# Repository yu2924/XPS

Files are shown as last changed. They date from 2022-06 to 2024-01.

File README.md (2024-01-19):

# XPS

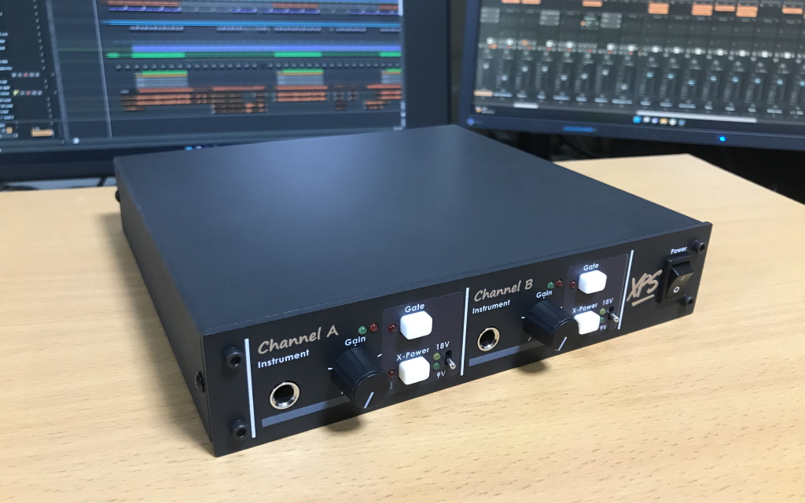
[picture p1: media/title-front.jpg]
  

ハードウェアプロジェクト**XPS**のデザインについてまとめます。

<!-- TOC -->

- [XPS](#xps)
  - [1. 概要](#1-概要)
  - [2. ツールとマテリアル](#2-ツールとマテリアル)
  - [3. 回路の略解](#3-回路の略解)
    - [3-1. 主電源 (XPS:PS-AC, XPS:PS-DC)](#3-1-主電源-xpsps-ac-xpsps-dc)
    - [3-2. バッファアンプ (XPS:Channel)](#3-2-バッファアンプ-xpschannel)
    - [3-3. 給電回路 (XPS:Channel:XPower)](#3-3-給電回路-xpschannelxpower)
    - [3-4. コントローラ (XPS:Channel:Controller) とファームウェア](#3-4-コントローラ-xpschannelcontroller-とファームウェア)
  - [4. 筐体と組み立て](#4-筐体と組み立て)
  - [補遺](#補遺)
  - [Appendix 1. 電気楽器の外側から給電する仕組み](#appendix-1-電気楽器の外側から給電する仕組み)
  - [Appendix 2. レギュレータの損失のシミュレーション](#appendix-2-レギュレータの損失のシミュレーション)
  - [Appendix 3. 平衡ドライバの素子感度](#appendix-3-平衡ドライバの素子感度)
  - [Appendix 4. フリーソフトでCMYKデータを出力する手順](#appendix-4-フリーソフトでcmykデータを出力する手順)

## 1. 概要

**XPS**はDTM用途を想定した、電気ギターなどの電気楽器をオーディオ機器の平衡ライン入力に接続するためのフロントエンドです。ハイインピーダンスのバッファアンプと、アクティブサーキットのための給電回路 [(Appendix 1)](#appendix-1-電気楽器の外側から給電する仕組み) を備えます。

* 独立2チャネル
* 1Uハーフラックサイズ
* AC電源: 100～115V|200～230V切替

**バッファアンプ**[^1]
* 入力インピータンス: 1MΩ typ.
* ゲイン可変範囲: 0～20dB typ.
* 入力スイング幅: ±7.0V typ.
* 出力スイング幅: ±9.9V typ.
* バンド幅: 1～1MHz typ. @Gain=0dB
* クリックレスミュート機能
* トランスレス平衡ライン出力、片極を接地してシングルエンド動作可能、600Ω 1μFの負荷を安定してドライブ可能 (要確認)

[^1]: 入出力のスイング幅やバンド幅は採用したオペアンプの種類に依存する

**給電回路**
* 出力電圧: 9V|18V切替
* 電流制限: 100mA/チャネル typ.
* 短絡・過熱・逆電圧・逆電流に対する保護

## 2. ツールとマテリアル

**ソフトウェアツール**
* 回路シミュレーション: [LTspice](https://www.analog.com/jp/design-center/design-tools-and-calculators/ltspice-simulator.html) XVII
* 回路作図: [BSch3V](https://www.suigyodo.com/online/schsoft.htm) 0.83.05
* PCB設計: [KiCad](https://www.kicad.org/) 6.0
* ファームウェア開発: [MPLAB X IDE](https://www.microchip.com/en-us/tools-resources/develop/mplab-x-ide) v6.00, [Atmel AVR GNU Toolchain](https://www.microchip.com/en-us/tools-resources/develop/microchip-studio/gcc-compilers) v3.62
* 筐体作図: [QCAD](https://qcad.org/) 3.27
* 筐体印刷データ作画: [Inkscape](https://inkscape.org/) 1.1
* 筐体印刷データCMYK出力: [Scribus](https://www.scribus.net/) 1.5.7
* 部品の3Dモデリング: [OpenSCAD](https://openscad.org/) 2021.01

**ハードウェアツール**
* AVRプログラマ: [MPLAB SNAP](https://www.microchip.com/en-us/development-tool/PG164100) or [MPLAB PICkit™ 4](https://www.microchip.com/en-us/development-tool/PG164140)、MPLAB X IDEと互換性のあるISPライタなら何でも
* DC電圧計: 電源回路の出力電圧を調節するために必要ですが、とりあえず3 1/2桁のDMMで十分です。
* オシロスコープ: 発振やオーバーシュートを観察するためにはアナログ帯域が少なくとも10MHz程度必要です。

**CMYK ICCプロファイル**
* [JapanColor2011 ICCプロファイル](https://japancolor.jp/icc.html)

**ブラシフォント**
* [Free Hey November Brush Font](https://www.behance.net/gallery/86877867/Free-Hey-November-Brush-Font)

**その他**
* ハンダとハンダゴテ、ニッパーとラジオペンチ、ヤスリ、3Dプリンタ、等々
* ビニル絶縁電線、スペーサー、ネジ、ワッシャー、アルミ板、等々

## 3. 回路の略解

[回路図](media/schematics.pdf)

### 3-1. 主電源 (XPS:PS-AC, XPS:PS-DC)

* トロイダルトランスを採用
* 古典的なドロッパ方式による11V・22Vの2レール、300mA出力
* レギュレータICにLT1963AとLT3015を採用
* 軽負荷時にレギュレータICの耐圧不足を補う電圧リミッタ

AC入力電圧範囲をなるべく広く取るため、出力電圧が低めのトランスとLDOを組み合わせ、リプル下限をなるべく持ち上げておくために平滑キャパシタは大きめに取っています。

レギュレータ回路の放熱について。ACライン電圧の許容範囲とトランスの変動率から、レギュレータ回路の入力電圧は幅広く変化します。負荷が重くなるほどトランスにおける電圧降下が大きくなるので、レギュレータ回路自体の損失が最大化するのは必ずしも負荷が最大の時ではありません。正確な値を求めるためには負荷変動とトランスの変動率をモデル化したシミュレーションが必要です [(Appendix 2)](#appendix-2-レギュレータの損失のシミュレーション)。
とはいえ、レギュレータ回路における損失の最悪値として {最大電圧降下×最大負荷電流} を考えてもそれほど大きな値ではないので、シャーシにしっかり熱結合させておけばヒートシンクとして十分です。元よりラックマウントする運用形態においてはシャーシ内の空気の循環は期待できないので、排熱は直接シャーシに逃がす以上に確実な方法はありません。

### 3-2. バッファアンプ (XPS:Channel)

* 単電源動作
* JFET入力オペアンプOPA1641[^2] を採用した非反転可変ゲインのヘッドアンプ
* オペアンプOPA1602[^3]を採用したトランスレス平衡ラインドライバ[^4]
* フォトリレーを使用したトランスミッションゲート

[^2]: JFET入力タイプのシングルオペアンプのLF356、OPA604などで代替可能 (要確認)
[^3]: ドライブ能力の高いデュアルオペアンプのNE5532、NJM4580などで代替可能 (要確認)
[^4]: モノリシックICで類似のものにはPMI (現ADI) SSM2142、TI DRV134、THAT 1646などがある

単電源動作ではグラウンドにリターン電流が流れるため音質の面では不利ですが、Hi-Fiオーディオが目的ではないので良しとします。

ラインドライバの差動バランスについて素子感度が高いので注意が必要です [(Appendix 3)](#appendix-3-平衡ドライバの素子感度)。理想的にはホットとコールドは互いに逆位相で等振幅になりますが、抵抗値のばらつきにより振幅のバランスが崩れます。差動ゲインが保たれているのであれば少々のアンバランスは問題になりませんが、大きく崩れるとスイング幅が狭まります。抵抗値の比が重要なので相対精度を保証された集合抵抗を利用するのが良さそうですが、ここでは入手性とパターン引き回しの容易さを重視して、ディスクリート抵抗の組み合わせを選別する方法を採用しました。

ラインドライバの位相補償キャパシタは10pFとしていますが、最適値は採用するオペアンプの種類によって異なります。小さ過ぎると発振し易くなります。基板単体で安定していても、ケーブルを接続すると数MHzの高周波で発振することがあります。大き過ぎると高域特性を鈍らせますが、不要な帯域を欲張るよりは安全側に倒しておくのも一法です。100pFでは100kHz程度でロールオフします。

給電回路のON/OFF操作により電気楽器側でポップ雑音の発生が予想できるので、適宜ミュート出来るようにトランスミッションゲートを設けます。フォトリレーを使用し、定電流ドライブに時定数を掛けることで遷移の際のクリック雑音を防ぎます。フォトリレーはゲート電位がフローティングしているため、信号の振幅に依存したON抵抗の変動は無く、歪みは発生しません。

### 3-3. 給電回路 (XPS:Channel:XPower)

* 2系統の電源レールを切り替えるマルチプレクサ
* レギュレータICにLT3066を採用
* ロジックインターフェース

制御可能なシャットダウン、設定可能な電流制限、パワーグッドフラグを備えます。既成のレギュレータICを採用するのはディスクリートと較べて簡単なのはもちろん、電流制限、熱制限、逆電流保護、逆出力保護など各種保護回路の充実も利点です。

### 3-4. コントローラ (XPS:Channel:Controller) とファームウェア

AVRマイコンのATtiny44Aでピークインジケータとスイッチ入力を制御します。クロックの飛び移りを低減するためなるべく低周波・低電圧で動作させるのが望ましいですが、当デザインでは8MHz 3.3V駆動としています[^5]。
* 信号レベル監視のためADCをフリーランモード、およそ19kHzのサンプリングレートで動作させます。ADC割り込みハンドラにおいて波形処理します。
* チャタリング除去のため、メインループにおいてスイッチ入力をおよそ5msの間隔でポーリングします。ポーリング間隔はADC割り込みをカウントして作り出します。
* 電気楽器側で発生するポップ雑音を自動的に遮断するため、給電回路のON/OFFや電圧切り替え時にトランスミッションゲートを連動します。
* 給電回路のパワーグッドフラグと主電源の電圧を監視し、保安動作をします。

[^5]: ブレッドボードでの簡易的な実験では、3.3V駆動の場合には5V駆動と比較してクロック由来の16MHzのスペクトルが6dB程度低下した

## 4. 筐体と組み立て

筐体はアルミの箱にアルミパネルを組み合わせた二重パネル構造で、ジャックやポテンショメータの固定ナットを隠蔽してすっきりさせます (図4-1)。見栄えは向上しますが[^6]、コストも上がります。製作例ではタカチ社のカスタム加工サービスを利用し、シャーシにはMBFシリーズ、アルミパネルにはNPシリーズを組み合わせました。インクジェット印刷が利用できますが、CMYK色データの用意が必要です[(Appendix 4)](#appendix-4-フリーソフトでcmykデータを出力する手順)。  
スペーサやスイッチキャップ、治具などの作成には3Dプリンタを活用します。  
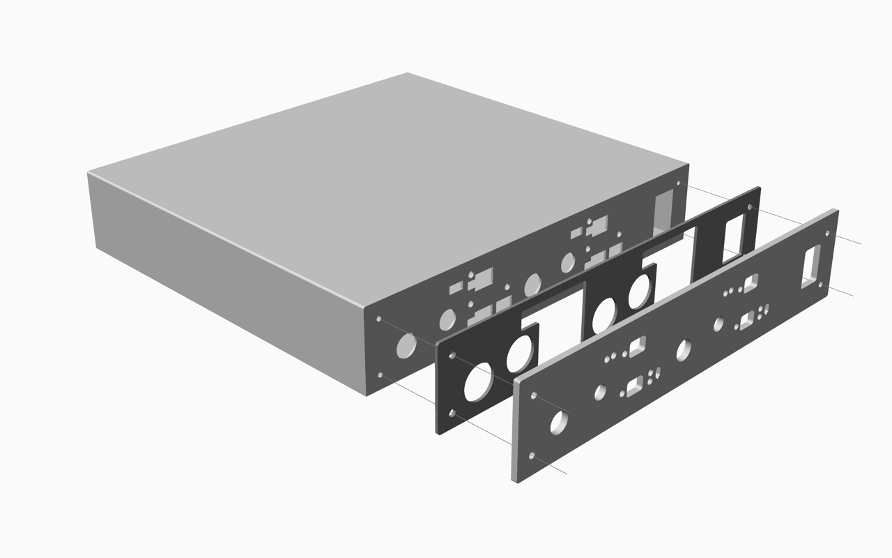
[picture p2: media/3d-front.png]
  
**図4-1. 二重パネル構造**  

[^6]: 個人の主観による



**図4-2. 基板の組み込み**  

主電源レギュレータ基板 (XPS:PS-DC) はアルミブロックを介してシャーシと熱結合します(図4-3, 4-4)。  
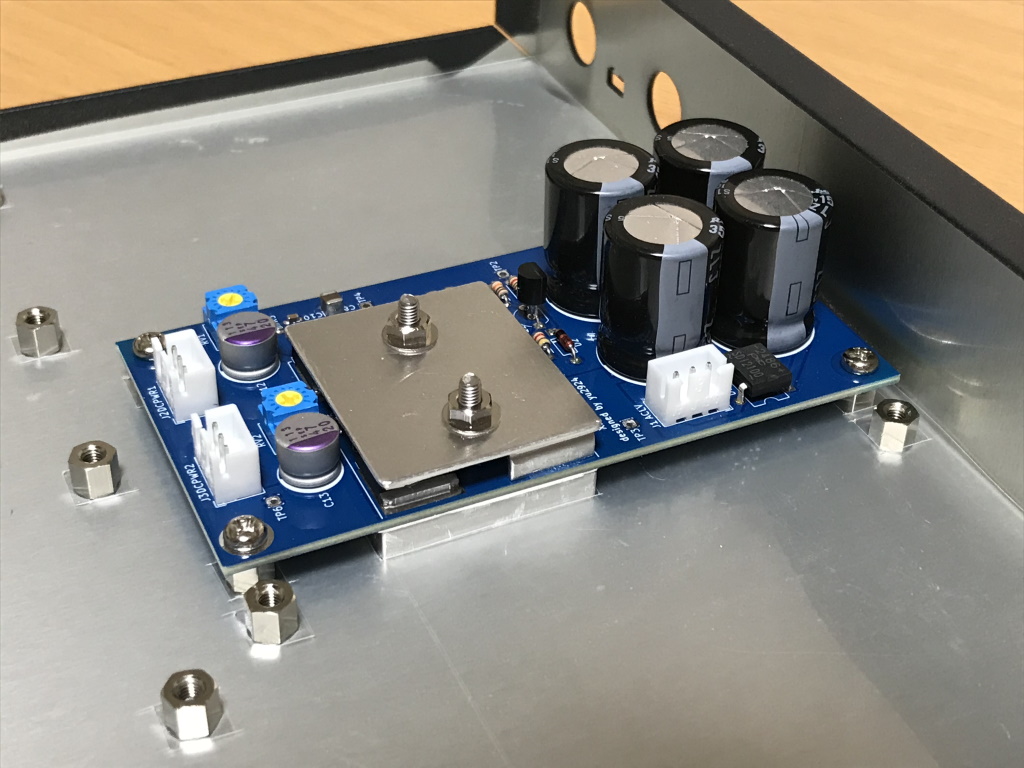
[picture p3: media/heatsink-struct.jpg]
   
**図4-3, 4-4. 主電源のヒートシンク構造**  

バッファアンプ基板 (XPS:Channel) と 出力ジャック基板 (XPS:OutputConnector) では、ジャックやポテンショメータをハンダで固定する際にプリントしたスペーサを合わせて、穴位置のずれを防ぎます (図4-5)。  
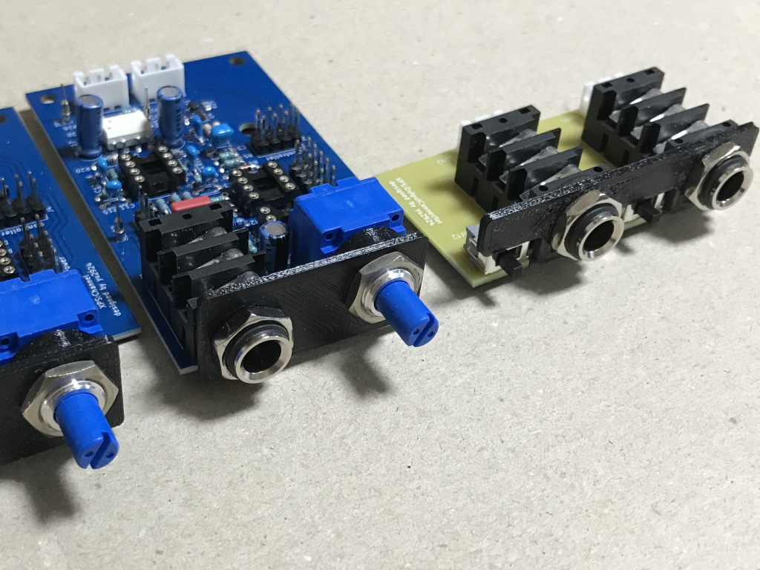
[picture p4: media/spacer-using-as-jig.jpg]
  
**図4-5. スペーサを固定治具として使用**  

ジャックやポテンショメータはシャーシマウントとし、ケーブルの挿抜やツマミ操作がハンダ部分に機械的なストレスを与えにくい構造です (図4-6)。  
  
**図4-6. ジャックやポテンショメータを直接シャーシに固定**  

給電回路基板 (XPS:Channel:XPower) とコントローラ基板 (XPS:Channel:Controller) は、バッファアンプ基板 (XPS:Channel)の子基板としてピンヘッダ・ソケットを介して接続します。(図4-7)  
  
**図4-7. 子基板の装着**  

操作パネル基板 (XPS:Channel:ControlPanel) の組み立てには、治具をプリントしてLEDとスイッチの位置決めに使います。(図4-8, 4-9)  
コントローラ基板 (XPS:Channel:Controller) とはフラットケーブルで接続します。  
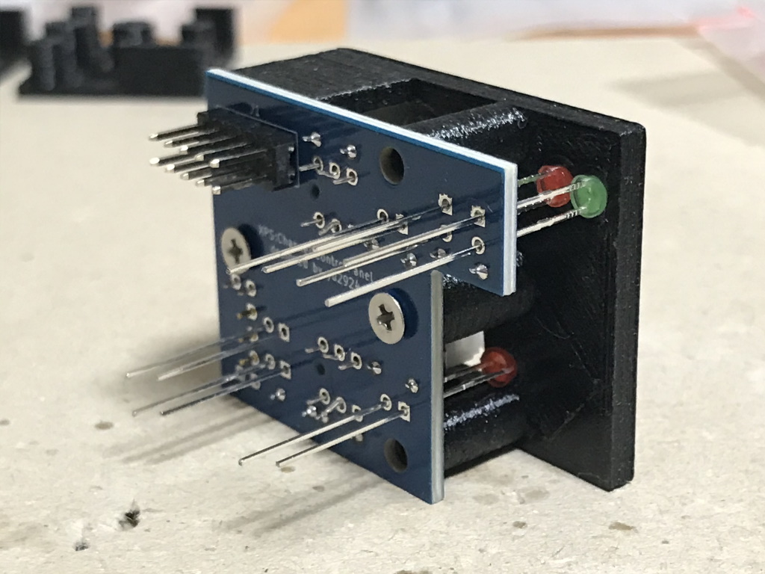
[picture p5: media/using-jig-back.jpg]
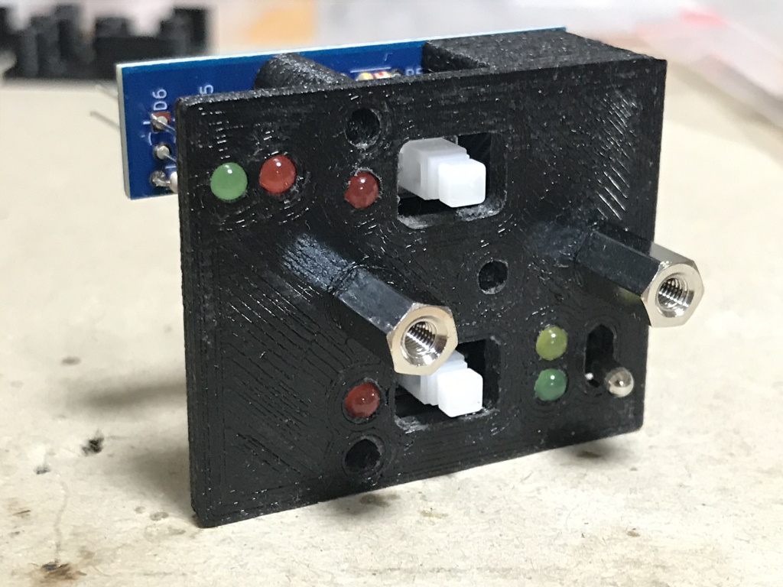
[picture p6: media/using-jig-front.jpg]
   
**図4-8, 4-9. 治具を使用した位置決め**  

フロントパネルはM3ボルトでシャーシに固定します。ハーフラックトレイに乗せるため、シャーシの底面を2mmほど浮かすようになっています (図4-10)。  
  
**図4-10. フロントパネル構造**  

**組み立て後の調節手順**
1. 主電源レギュレータ基板 (XPS:PS-DC) の出力電圧を調節する。あらかじめRV1とRV2を左手最小位置に回し切っておき、主電源をONにする。最初にRV1で11Vレールを調節し、次にRV2で22Vレールを調節する。11Vレールは9V給電のために最低でも11Vあった方が良いが、22Vレールは実際には21V程度あれば十分である。
2. ファームウェアを書き込む。主電源を入れた状態でコントローラ基板 (XPS:Channel:Controller) のISPヘッダにAVRライタを接続し、書き込む。
3. 給電回路基板 (XPS:Channel:XPower) の出力電圧を調節する。あらかじめRV1とRV2を左手最小位置に回し切っておき、給電回路をONにする。最初にRV1で9Vを調節し、次にRV2で18Vを調節する。厳密である必要は無く、長いケーブルを介して給電することを考えると少し高めに設定しておいても良いのではないかと思う。  
:warning:18V側の上がり過ぎに注意する。給電回路に採用した**LT3066の最大定格出力は20Vである**ため、過渡的なオーバーシュートを含め20Vを超えてはいけない。
4. ピークインジケータの感度を調節する。バッファアンプ基板 (XPS:Channel) にオーディオ信号を入力し、テストポイントTP3において±7Vpeakにスイングしたときにインジケータの赤ランプが点灯するようにコントローラ基板 (XPS:Channel:Controller) のRV1を調節する。

---

## 補遺

今後の課題や改良点などを追記します。

**トランスミッションゲートのフィードスルー抑止**

フォトリレーを利用したトランスミッションゲートにおいて、カットオフ減衰率の不足を感じることがありました。ハイゲインの歪みプロセッサに入力した場合などで特に顕著で、漏れてくる音がはっきり聞こえます。もう一組のフォトリレーで双投スイッチを構成することにより改善できるはずです。



**正負両電源化**

今回の制作では電源レールの数を抑えるため、バッファアンプを単電源動作させることになりました。電源レールを増やすにはトランスの独立した2次巻線がレールの数だけ必要です。今回は簡単確実なドロッパ電源を利用しましたが、スイッチング電源の導入も検討して良いと思います。

---

## Appendix 1. 電気楽器の外側から給電する仕組み

アクティブサーキットを内蔵した電気ギターなどの電気楽器によく見られる仕組みとして、出力のTRSジャックにTSプラグを差し込むことでsleeve端子とring端子を短絡させ、バッテリー接続をONするものがあります (図A1-1)。  
  
**図A1-1. TRSジャックを使ったバッテリースイッチ**  

このような仕組みにおいては、バッテリーの代わりに短絡クリップ (図A1-2) を繋いでおけば、TRSケーブルのring端子を経由してアクティブサーキットに給電することができます (図A1-3)。楽器の改造は必要ありません。当デザインではこの方法を採用しています。  
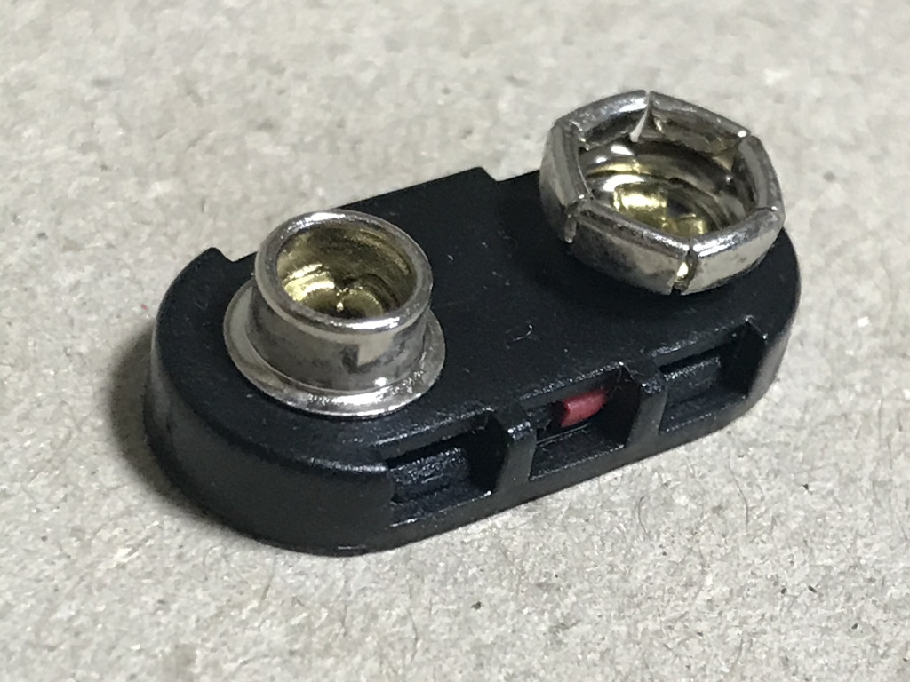
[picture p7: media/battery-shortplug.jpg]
  
**図A1-2. バッテリースナップを加工して作成した短絡クリップの例**  
  
**図A1-3. TRSケーブルを使った外部からの給電**  

>市販の製品の中にも、同様な方法でアクティブサーキットに給電できるものがありました。(要確認)
>* [EMG Power Supplies](https://www.emgpickups.com/parts/power-supplies.html)
>* Line6 Variax XPS-AB, XPS-Mini, XPS-DI
>* Steinberger A-100 Phantom Power Supply

一方、絶縁された連動スイッチでバッテリー接続をONするタイプの電気楽器も存在します (図A1-4)。このような仕組みでは、ジャックを介して外部から給電することは出来ません。  
  
**図A1-4. 絶縁された連動スイッチによるバッテリースイッチ**  

## Appendix 2. レギュレータの損失のシミュレーション

レギュレータの放熱方法について検討するため、パワー半導体における損失をシミュレーションしてみます。  
トランスの変動率仕様あるいは実測値からおよその巻線抵抗を割り出して設定します。回路は実際のものと全く同じである必要はありません。入出力電位差と負荷電流を揃えれば損失の値はおのずと等しくなります。ここで負荷を0～300mAまでスイープさせてみます。(図A2-1)  
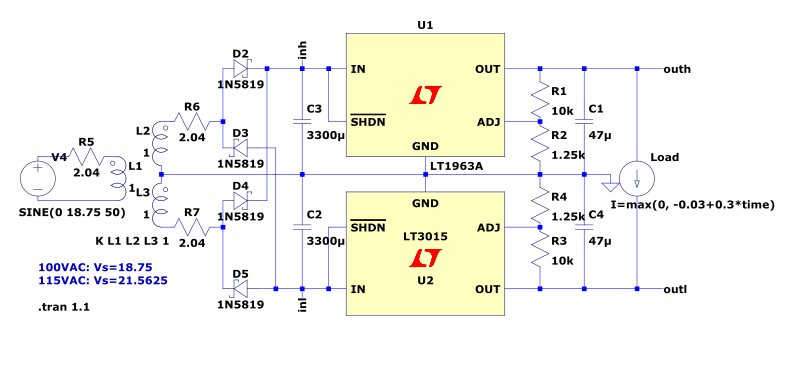
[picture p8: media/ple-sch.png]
  
**図A2-1. 損失シミュレーション回路**  

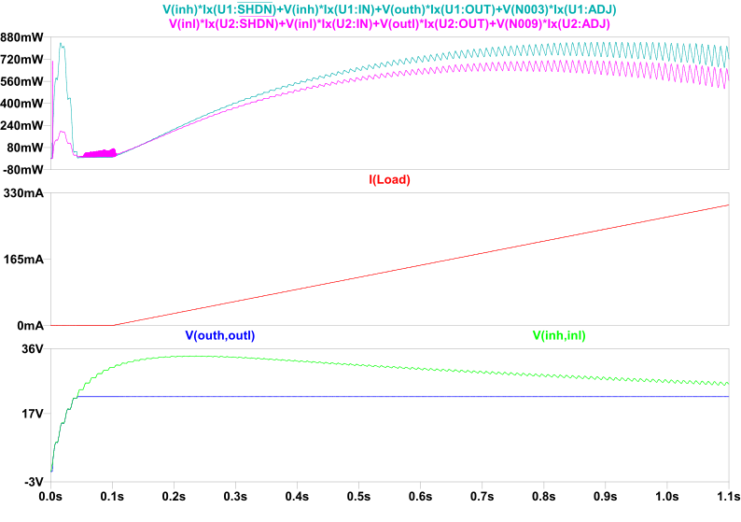
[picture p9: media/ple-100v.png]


**図A2-2. 損失シミュレーション (100V AC)**  

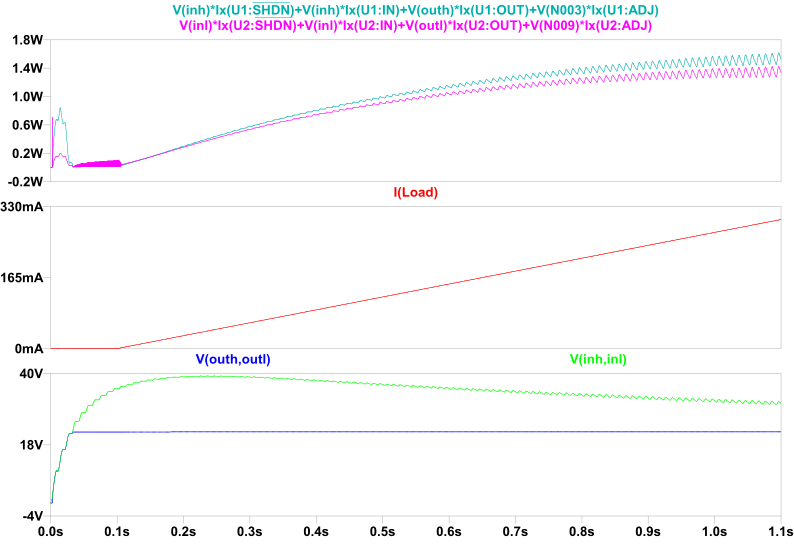
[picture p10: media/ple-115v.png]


**図A2-3. 損失シミュレーション (115V AC)**  

2つのレギュレータICにおける最大損失はおよそ以下の表のように読み取れます。

| |LT1963A|LT3015|
|---|---:|-----:|
|100V AC (図A2-2)|  750mW| 630mW|
|115V AC (図A2-3)| 1.5W|  1.3W|

これらの値を元に、許容可能な温度上昇と放熱経路の熱抵抗を勘案して放熱の仕組みを決定します。

## Appendix 3. 平衡ドライバの素子感度

平衡ドライバにおいて抵抗値のばらつきが差動バランスに与える影響をシミュレーションしてみます。
差動アンプ対の8本の抵抗に0.1%のばらつきを加えてモンテカルロ解析します (図A3-1)。オペアンプモデルにはTI社の提供するPSpiceモデルを利用していますが、理想オペアンプや他のモデルでも構いません。  
ばらつきの無い理想状態ではバランスが取れており、V(hot)とV(cold)の両極は互いに逆位相で等振幅です (図A3-2)。  
ばらつきを加えた場合には差動振幅 V(hot,cold) にはあまり影響を与えないものの、両極の振幅バランスが崩れることがわかります (図A3-3)。  
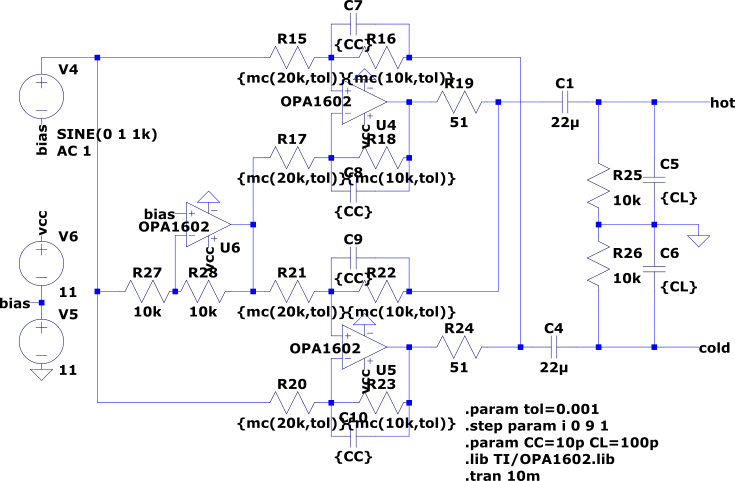
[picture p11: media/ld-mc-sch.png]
  
**図A3-1. モンテカルロ解析する回路**

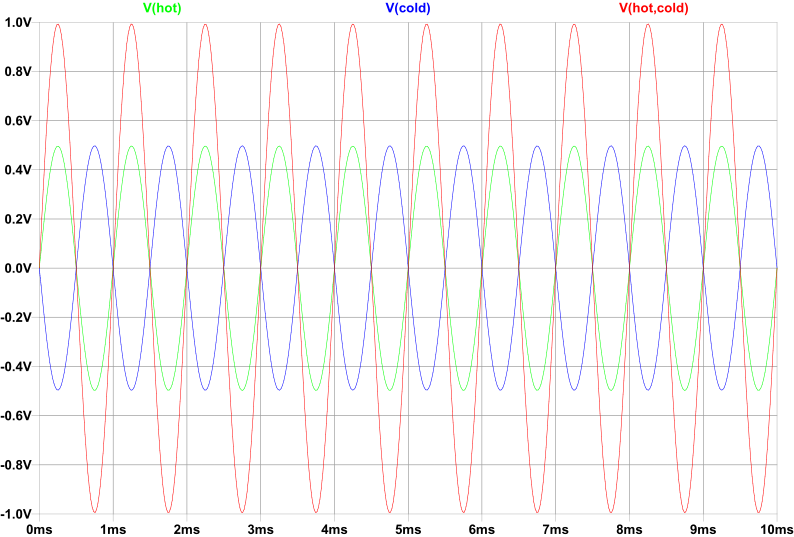
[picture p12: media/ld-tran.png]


**図A3-2. ばらつきの無い理想状態**  

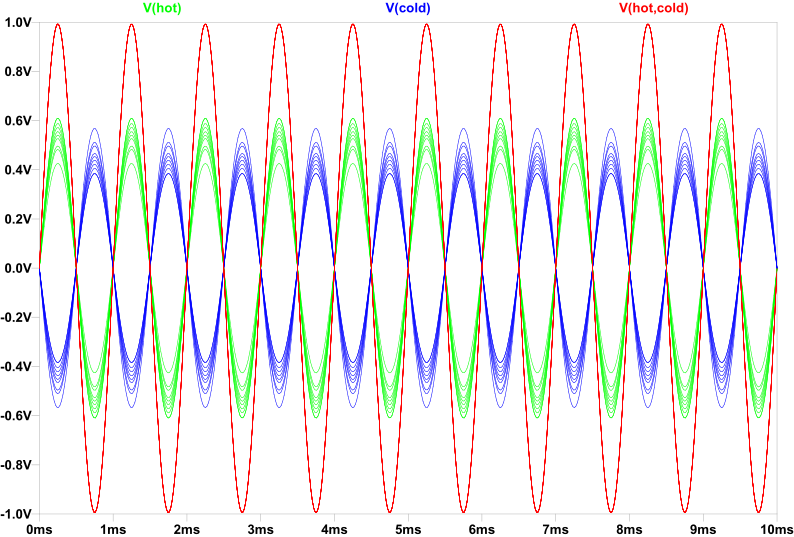
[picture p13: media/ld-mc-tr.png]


**図A3-3. ばらつきを加えた状態**  

バランスの良好な抵抗素子の組み合わせを見つける方法ですが、ブレッドボードで仮組みをして入力信号を与え、出力端をオシロスコープで観察しながら差し替え試行錯誤するのが手軽です (図A3-4)。ここではPCで生成した1kHzのサイン波を入力しています。使い込まれて劣化したブレッドボードやジャンプワイヤは接触抵抗が安定しないことがあり、注意が必要です。シミュレーションの結果を見ると、普通の1%精度のディスクリート抵抗では厳しいのではという印象を受けますが、実際に組んでみると意外と何とかなりそうな感触です。目標としては、振幅の差異が20％程度に収まっていれば実用上は十分で、10%以内なら上出来だと思います。  
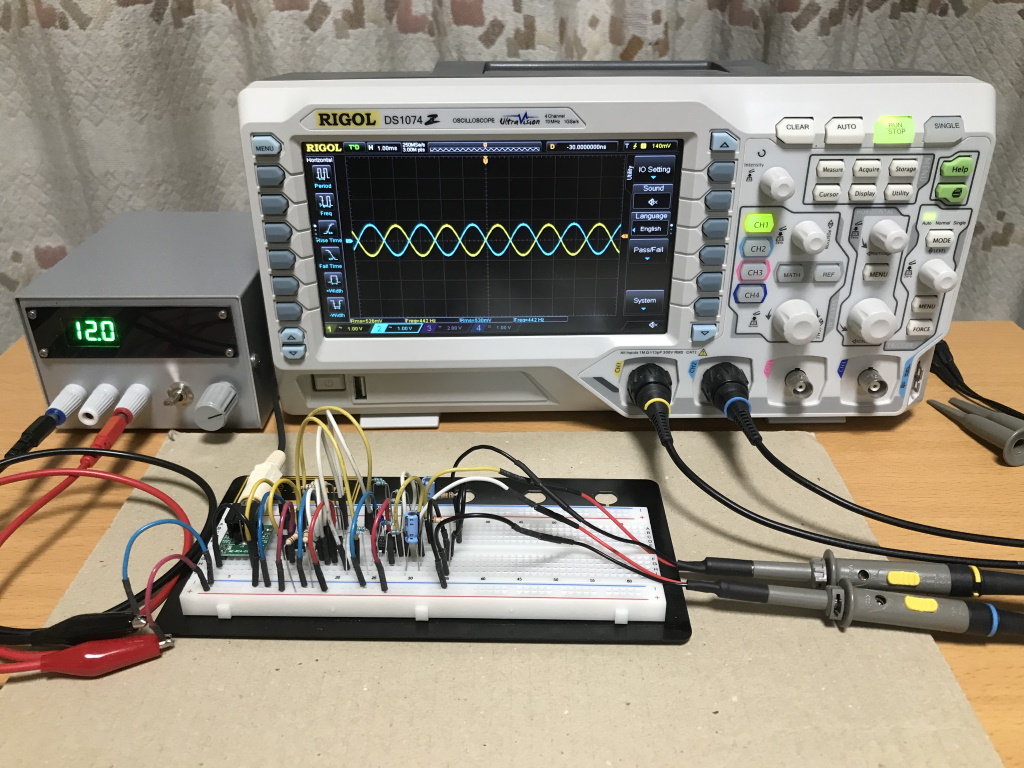
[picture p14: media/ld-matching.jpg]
  
**図A3-4. 仮組みで抵抗素子の組み合わせを試行**  

## Appendix 4. フリーソフトでCMYKデータを出力する手順

タカチ社のカスタム加工サービスを利用する際に、インクジェット印刷を依頼するためにはCMYK色のデータが必要になります。Adobe Illustratorを利用できればAI形式で出力して事足りるのですが、さもなければ以下の手順を踏んでPDF形式のデータを作成できます。

1. Inkscapeを利用してSVGを作成する。Inkscapeは直接CMYKデータを出力できないが、ドキュメントプロパティにCMYKプロファイルを設定して、カラープロファイルの範囲に収まる色だけを使用して描画することができる。
2. Scribusを利用してSVGからCMYKのPDFを出力する。  
まずSVGを読み込み、**File|Document Setup|Color Management**からCMYKプロファイルが割り当てられていることを確認する。
3. 次に**Edit|Colours and Fills**から、全ての使用色が**Colour Model: CMYK**であることを確認する。
4. 最後に**File|Export|Save as PDF**から、**Colour**タブで**Output Intended For: Printer**であることを確認して出力する。

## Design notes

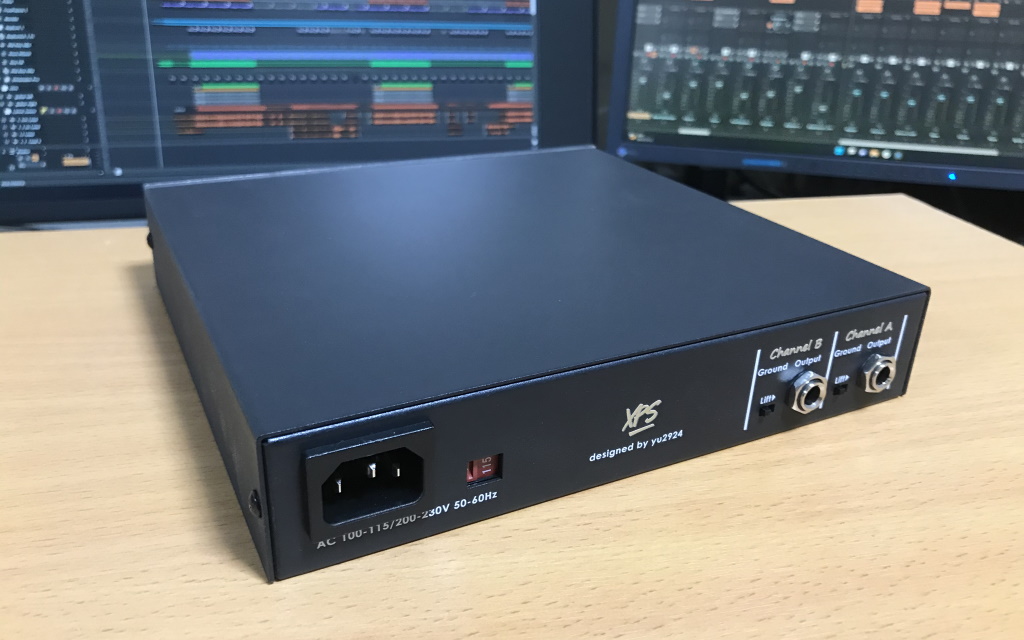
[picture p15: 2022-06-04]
media/title-back.jpg

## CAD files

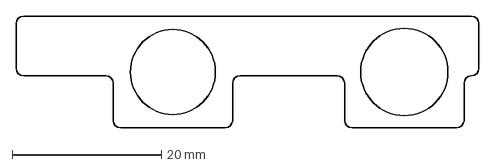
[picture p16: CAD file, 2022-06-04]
enclosure/3dprints/OutputConnectorSpacerPlane.dxf
62.0 x 15.0 mm

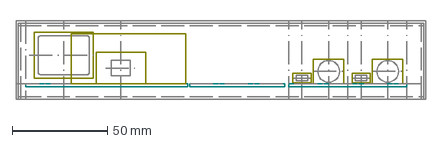
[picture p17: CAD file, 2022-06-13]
enclosure/drafts/chassis-back.dxf
215.0 x 41.0 mm

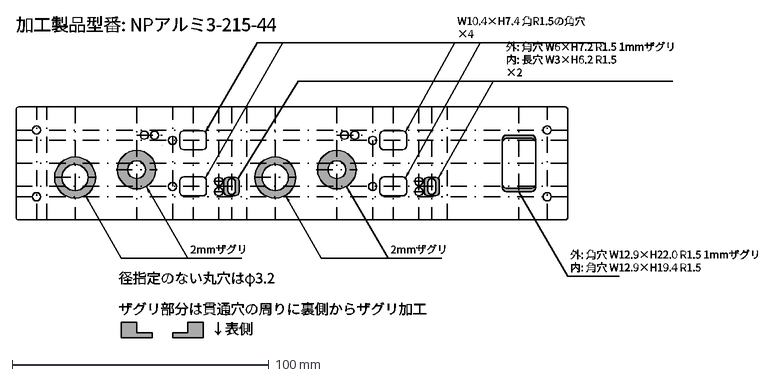
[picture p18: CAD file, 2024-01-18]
enclosure/machining/frontpanel.dxf
加工製品型番: NPアルミ3-215-44
ザグリ部分は貫通穴の周りに裏側からザグリ加工
↓表側
2mmザグリ
外: 角穴 W12.9×H22.0 R1.5 1mmザグリ 内: 角穴 W12.9×H19.4 R1.5
径指定のない丸穴はφ3.2
W10.4×H7.4 角R1.5の角穴 ×4
外: 角穴 W6×H7.2 R1.5 1mmザグリ 内: 長穴 W3×H6.2 R1.5 ×2

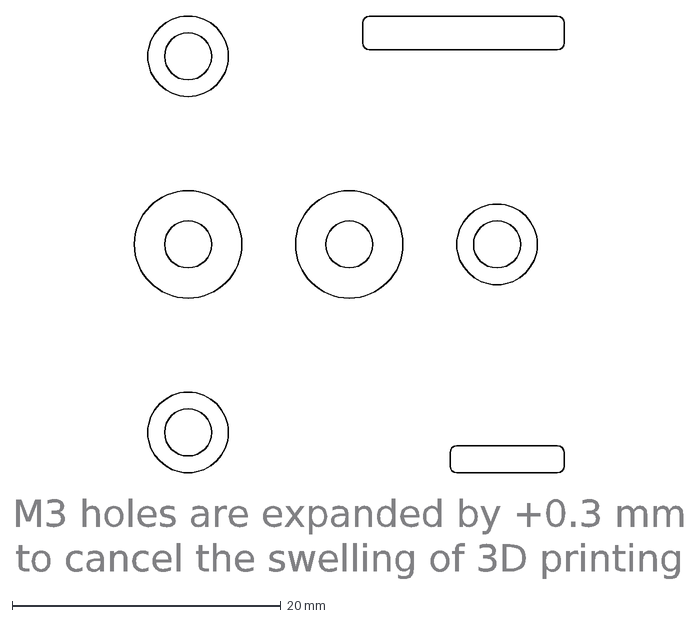
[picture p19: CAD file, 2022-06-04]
enclosure/3dprints/ControlPanelSpacerPost.dxf
M3 holes are expanded by +0.3 mm to cancel the swelling of 3D printing

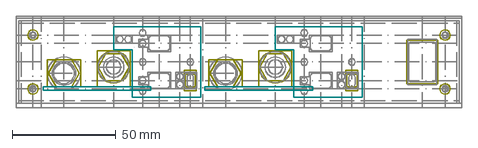
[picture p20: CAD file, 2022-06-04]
enclosure/drafts/chassis-front.dxf
215.0 x 44.0 mm

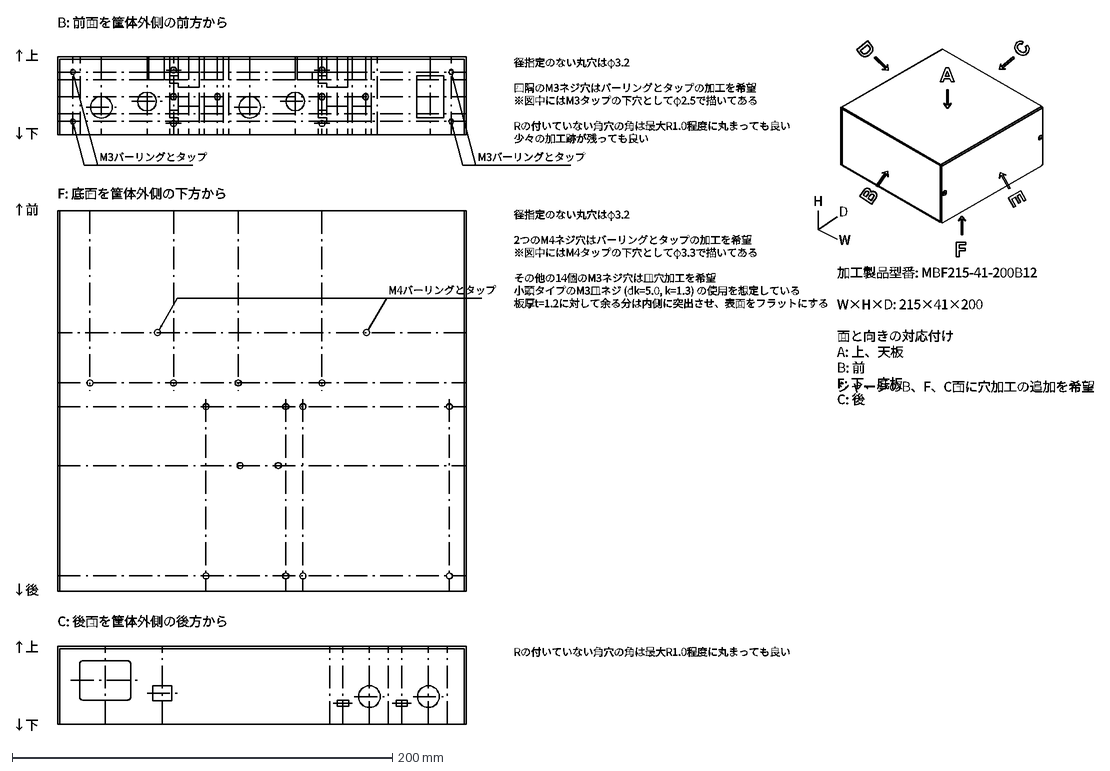
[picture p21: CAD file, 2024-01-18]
enclosure/machining/chassis.dxf
径指定のない丸穴はφ3.2 2つのM4ネジ穴はバーリングとタップの加工を希望 ※図中にはM4タップの下穴としてφ3.3で描いてある その他の14個のM3ネジ穴は皿穴加工を希望 小頭タイプのM3皿ネジ (dk=5.0, k=1.3) の使用を想定している 板厚t=1.2に対して余る分は内側に突出させ、表面をフラットにする
M4バーリングとタップ
Rの付いていない角穴の角は最大R1.0程度に丸まっても良い
径指定のない丸穴はφ3.2 四隅のM3ネジ穴はバーリングとタップの加工を希望 ※図中にはM3タップの下穴としてφ2.5で描いてある Rの付いていない角穴の角は最大R1.0程度に丸まっても良い 少々の加工跡が残っても良い
M3バーリングとタップ
加工製品型番: MBF215-41-200B12 W×H×D: 215×41×200 面と向きの対応付け A: 上、天板 B: 前 F: 下、底板 C: 後
B: 前面を筐体外側の前方から
C: 後面を筐体外側の後方から
F: 底面を筐体外側の下方から
↑前
↑上
↓後
↓下
W
H
D
シャーシのB、F、C面に穴加工の追加を希望

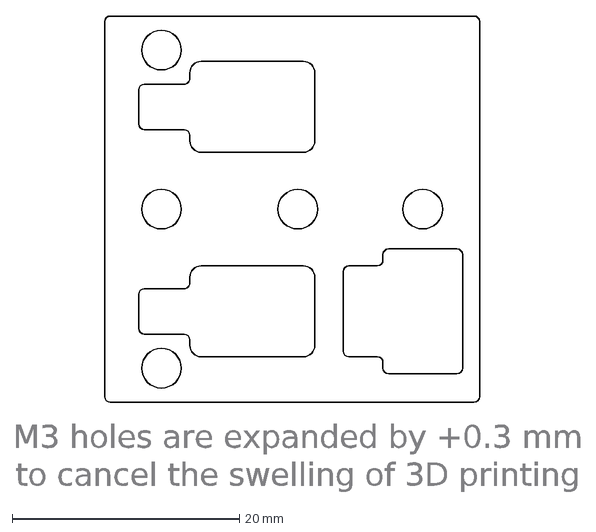
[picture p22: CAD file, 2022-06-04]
enclosure/3dprints/ControlPanelSpacerPlane.dxf
M3 holes are expanded by +0.3 mm to cancel the swelling of 3D printing

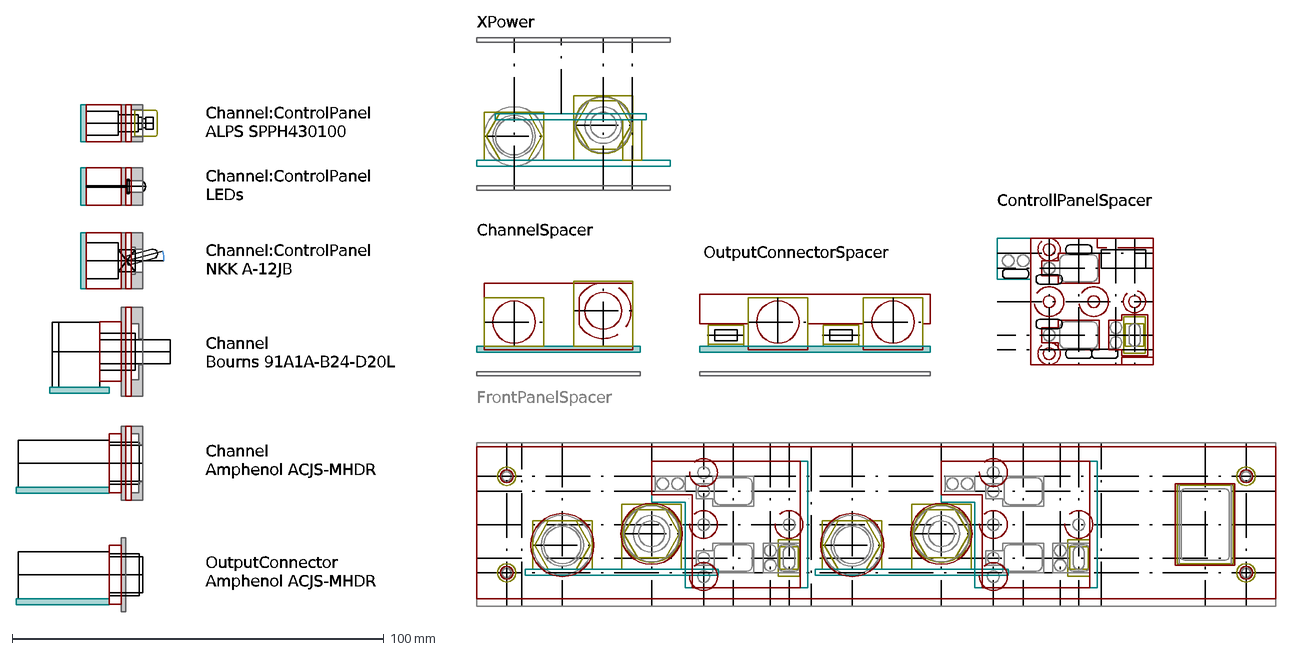
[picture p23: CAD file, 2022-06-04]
enclosure/drafts/spacing.dxf
Channel Amphenol ACJS-MHDR
OutputConnector Amphenol ACJS-MHDR
Channel Bourns 91A1A-B24-D20L
Channel:ControlPanel NKK A-12JB
Channel:ControlPanel LEDs
ChannelSpacer
OutputConnectorSpacer
ControllPanelSpacer
Channel:ControlPanel ALPS SPPH430100
FrontPanelSpacer
XPower

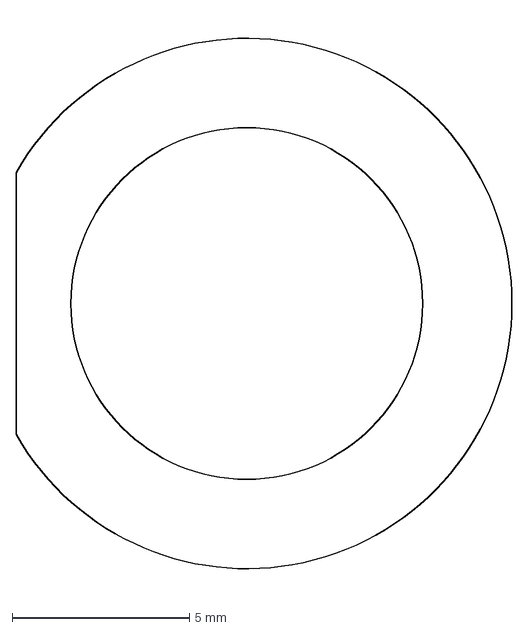
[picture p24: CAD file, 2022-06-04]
enclosure/3dprints/ChannelSpacerPost.dxf
14.0 x 16.2 mm

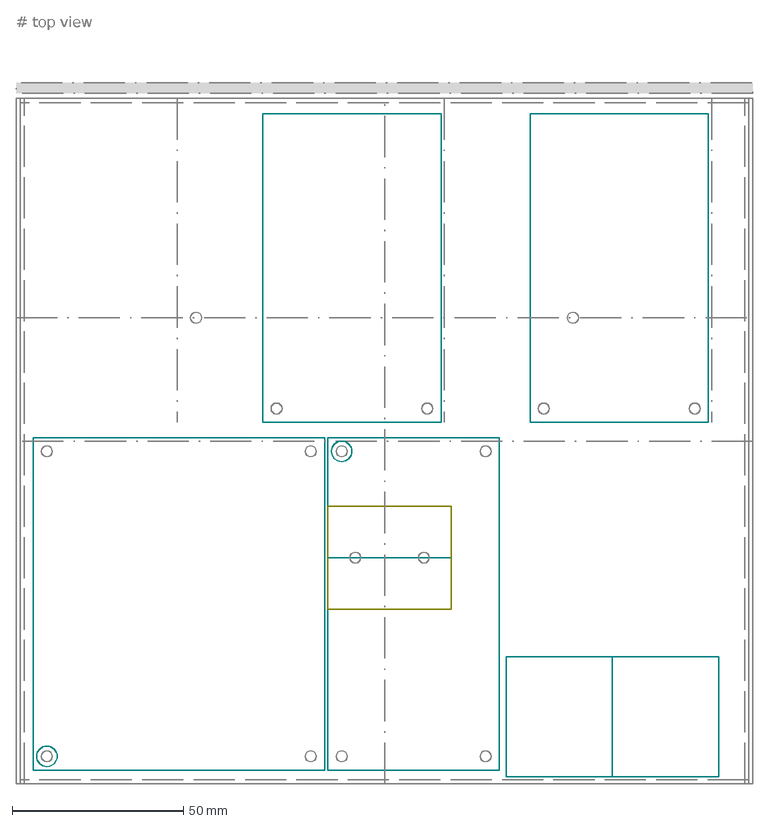
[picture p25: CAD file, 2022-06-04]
enclosure/drafts/chassis-bottom.dxf
# top view

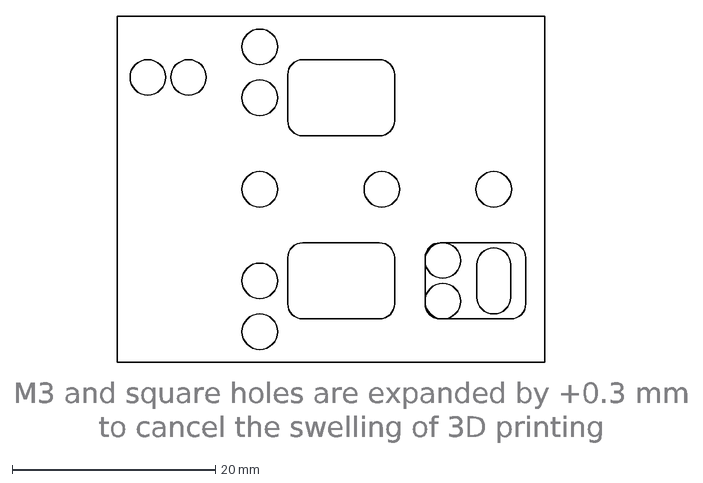
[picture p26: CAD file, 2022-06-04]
enclosure/3dprints/ControlPanelJigPlane.dxf
M3 and square holes are expanded by +0.3 mm to cancel the swelling of 3D printing

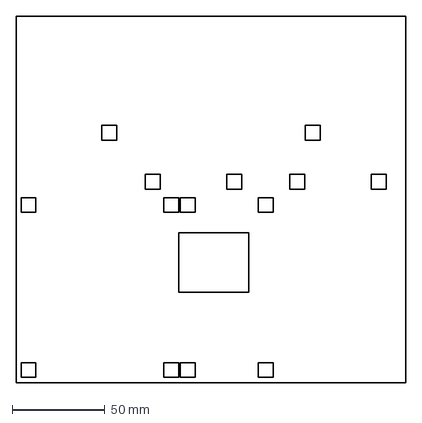
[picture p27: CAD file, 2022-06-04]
enclosure/drafts/insulation-sheet.dxf
210.2 x 197.6 mm

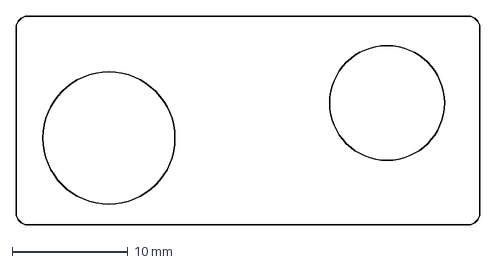
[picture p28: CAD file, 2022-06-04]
enclosure/3dprints/ChannelSpacerPlane.dxf
40.0 x 18.0 mm

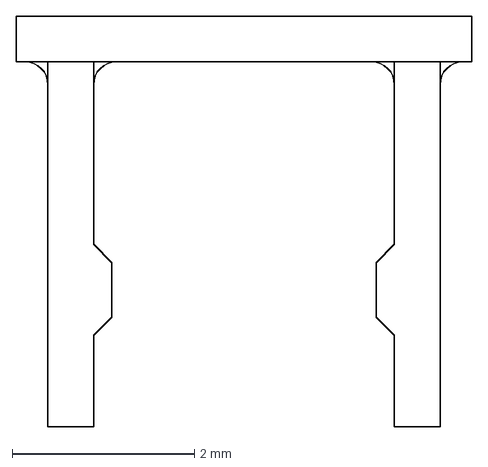
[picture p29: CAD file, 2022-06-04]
enclosure/3dprints/SwitchCapStemXsect.dxf
5.00 x 4.50 mm

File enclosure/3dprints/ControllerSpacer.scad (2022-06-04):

$fn = 90;
dxy = 6;
sp = 4;
eps = 0.001;
trim = 0.3;

module spacer()
{
    do = 6;
    di = 3.2 + trim;
    t = 1;
    difference()
    {
        cylinder(h=t, d=do, center=false);
        translate([0, 0, -eps]) cylinder(h=t+eps*2, d=di, center=false);
    }
}

for(x = [-0.5, 0.5])
{
    translate([x * (dxy + sp), 0, 0]) spacer();
}

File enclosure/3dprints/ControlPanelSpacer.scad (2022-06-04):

$fn = 90;
dx = 33;
dy = 34;
sp = 4;

module spacer()
{
    t1 = 2;
    t2 = 9.4 - t1;
    translate([0, dy, 0])
        rotate(a=180, v=[1, 0, 0])
        {
            translate([0, 0, -t1])
                linear_extrude(height=t1, center=false)
                    import(file="ControlPanelSpacerPlane.dxf", layer="0");
            translate([0, 0, -t1-t2])
                linear_extrude(height=t2, center=false)
                    import(file="ControlPanelSpacerPost.dxf", layer="0");
        }
}

module jig()
{
    t1 = 2;
    t2 = 1;
    t3 = 9.4 + 1.2 + 1.5;
    translate([0, dy, 0])
        rotate(a=180, v=[1, 0, 0])
        {
            translate([0, 0, -t1])
                linear_extrude(height=t1, center=false)
                    import(file="ControlPanelJigPlane.dxf", layer="0");
            translate([0, 0, -t1-t2])
                linear_extrude(height=t2, center=false)
                    import(file="ControlPanelJigPlane.dxf", layer="1");
            translate([0, 0, -t1-t2-t3])
                linear_extrude(height=t3, center=false)
                    import(file="ControlPanelSpacerPost.dxf", layer="0");
        }
}

printjig = true;
printmulti = false;

if(printjig)
{
    translate([-dx/2,  -dy/2, 0]) jig();
}
else if(printmulti)
{
    translate([ sp/2, -dy/2, 0]) spacer();
    translate([-dx - sp/2, -dy/2, 0]) spacer();
}
else
{
    translate([-dx/2,  -dy/2, 0]) spacer();
}

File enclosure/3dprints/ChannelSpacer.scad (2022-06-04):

$fn = 90;
dx = 40;
dy = 18;
sp = 4;

module spacer()
{
    trim = 0.0;
    twsh = 1.5;
    t1 = 3.3 - twsh - trim;
    t2 = 5.85 - trim;
    translate([0, dy, 0])
        rotate(a=180, v=[1, 0, 0])
        {
            union()
            {
                translate([0, 0, -t1])
                    linear_extrude(height=t1, center=false)
                        import(file="ChannelSpacerPlane.dxf", layer="0");
                translate([0, 0, -t2])
                    linear_extrude(height=t2, center=false)
                        import(file="ChannelSpacerPost.dxf", layer="0");
            }
        }
}

printmulti = false;

if(printmulti)
{
    translate([-dx/2,  sp/2, 0]) spacer();
    translate([-dx/2, -dy - sp/2, 0]) spacer();
}
else
{
    translate([-dx/2,  -dy/2, 0]) spacer();
}

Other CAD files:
enclosure/3dprints/FrontPanelSpacerPlane.dxf
enclosure/3dprints/FrontPanelSpacer.scad
enclosure/3dprints/FrontPanelWasher.scad
enclosure/3dprints/JackWasher.scad
enclosure/3dprints/OutputConnectorSpacer.scad
enclosure/3dprints/SolidSwitchCap.scad
enclosure/3dprints/SwitchCap.scad
enclosure/3dprints/SwitchCapStem.scad

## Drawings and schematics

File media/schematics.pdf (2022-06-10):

### XPS:Channel

### XPS:OutputConnector

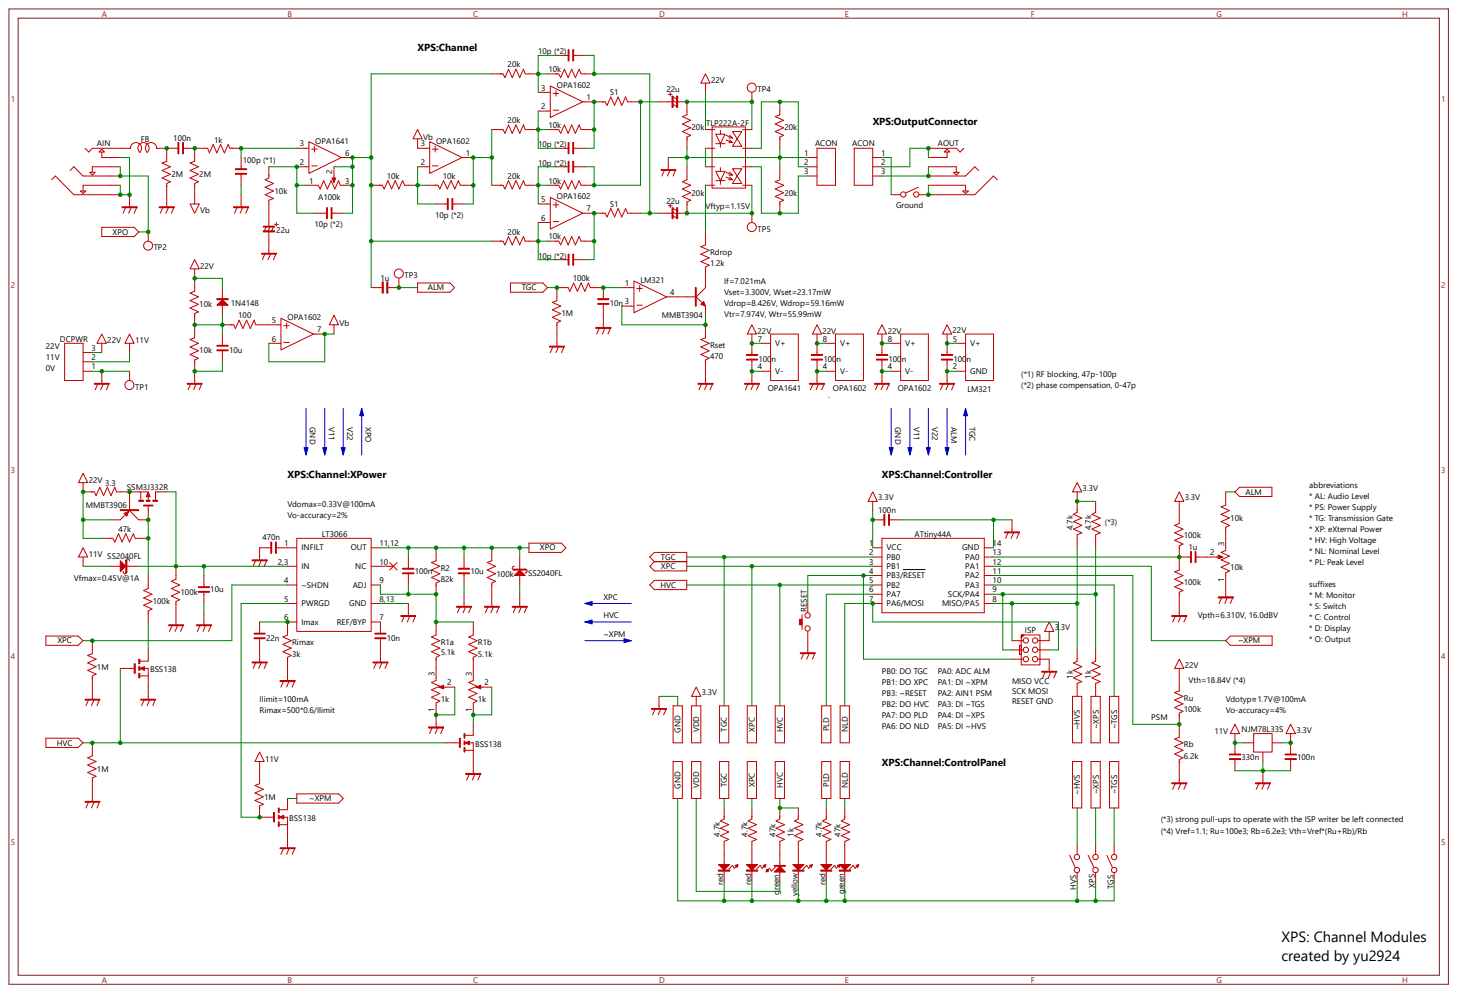
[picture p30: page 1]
H XPS: Channel Modules; created by yu2924; If=7.021mA Vset=3.300V, Wset=23.17mW Vdrop=8.426V, Wdrop=59.16mW Vtr=7.974V, Wtr=55.99mW; Vfmax=0.45V@1A; Vftyp=1.15V; Ilimit=100mA Rimax=500*0.6/Ilimit; MISO VCC SCK MOSI RESET GND; PA0: ADC ALM PA1: DI ~XPM PA2: AIN1 PSM PA3: DI ~TGS PA4: DI ~XPS PA5: DI ~HVS; PB0: DO TGC PB1: DO XPC PB3: ~RESET PB2: DO HVC PA7: DO PLD PA6: DO NLD; Vpth=6.310V, 16.0dBV; Vdotyp 1.7V@100mA ≅ Vo-accuracy=4%; Vth=18.84V (*4)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

abbreviations
* AL: Audio Level
* PS: Power Supply
* TG: Transmission Gate
* XP: eXternal Power
* HV: High Voltage
* NL: Nominal Level
* PL: Peak Level

XPS:Channel:ControlPanel

(*3) strong pull-ups to operate with the ISP writer be left connected
(*4) Vref=1.1; Ru=100e3; Rb=6.2e3; Vth=Vref*(Ru+Rb)/Rb

### XPS:PS-AC

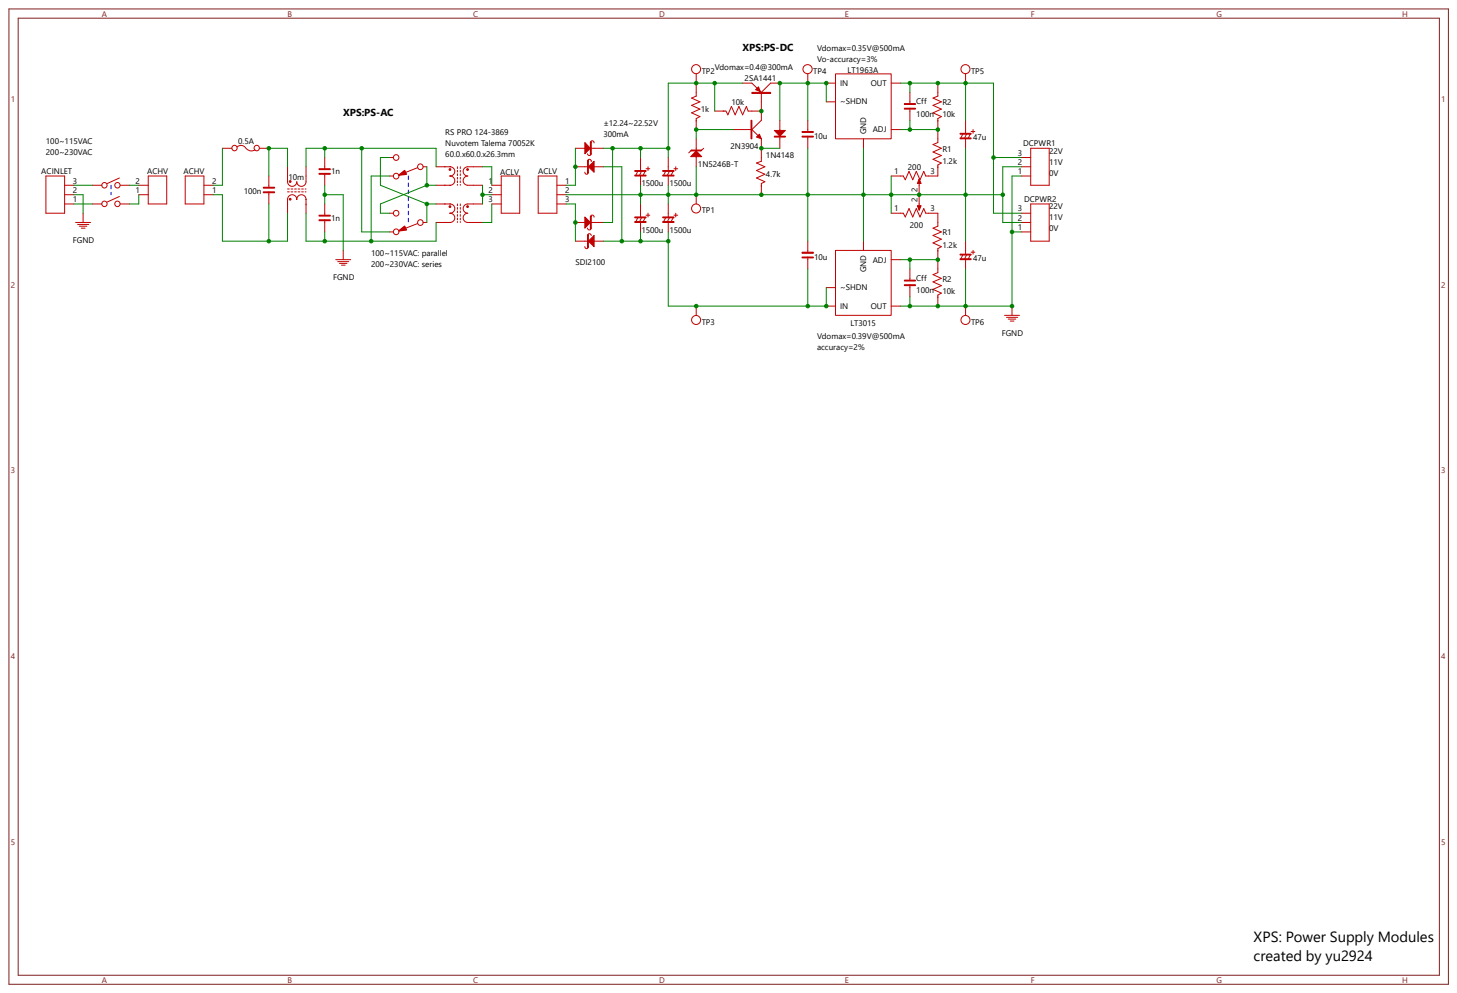
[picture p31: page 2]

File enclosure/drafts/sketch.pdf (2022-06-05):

# Channel A

Channel B | Power

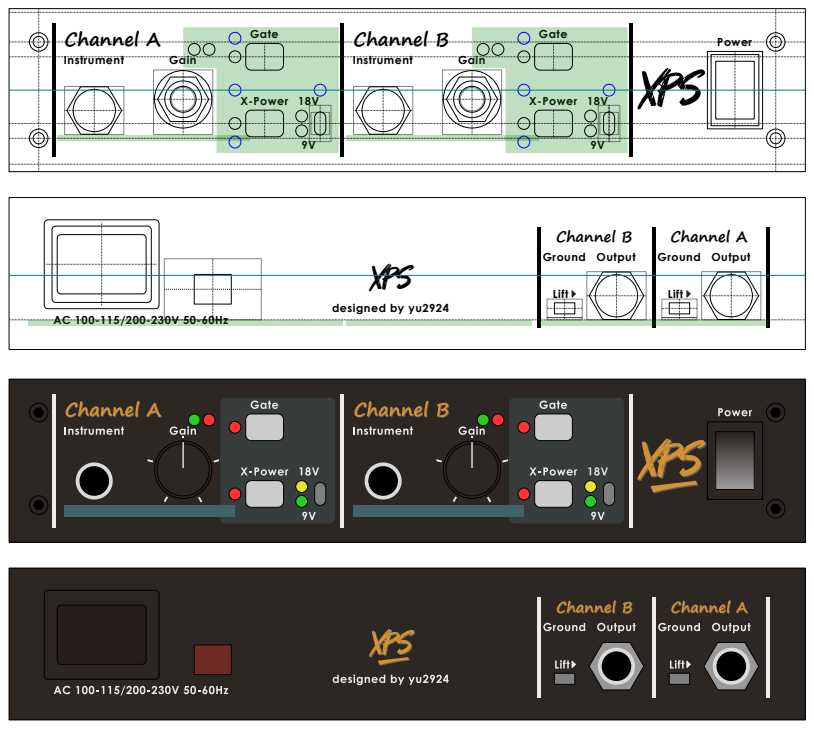
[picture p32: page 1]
Instrument; Gain; X-Power; Gate; XPS; designed by yu2924; Channel B; Channel A; Ground Output; Output Ground

XP Lift Lift S

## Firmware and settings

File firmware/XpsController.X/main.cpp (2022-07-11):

//
//  main.cpp
//  XpsController
//
//  created by yu2924 on 2021-11-11
//

#include <avr/io.h>
#include <avr/interrupt.h>
#include <avr/sleep.h>
#include <avr/power.h>
#define F_CPU 8000000L
#include <util/delay.h>
#include <util/atomic.h>

inline uint8_t getbit(uint8_t v, uint8_t ibit) { return (v >> ibit) & 0x01; }
inline void setbit(volatile uint8_t& vref, uint8_t ibit, uint8_t v) { vref = (vref & ~(1 << ibit)) | (v << ibit); }
inline void modifybyte(volatile uint8_t& vref, uint8_t m, uint8_t v) { vref = (vref & ~m) | (v & m); }
inline void atomicsetbit(volatile uint8_t& vref, uint8_t ibit, uint8_t v) { ATOMIC_BLOCK(ATOMIC_FORCEON) { setbit(vref, ibit, v); } }
inline void atomicmodifybyte(volatile uint8_t& vref, uint8_t m, uint8_t v) { ATOMIC_BLOCK(ATOMIC_FORCEON) { modifybyte(vref, m, v); } }

template<class T> T tmin(T a, T b) { return a < b ? a : b; }
template<class T> T tmax(T a, T b) { return a < b ? b : a; }
template<class T> T tlimit(T l, T h, T v) { return tmax(l, tmin(h, v)); }
template<class T> T tabs(T v) { return (0 <= v) ? v : -v; }

// --------------------------------------------------------------------------------
// building blocks

#define USE_CR 1
#if USE_CR
//
// CR high pass filter
// tc=1/(2*pi*fc)
// y=x-s; s=s+(x-s)*(2*pi*fc);
//
struct AcCoupler
{
	int32_t s, y;
	AcCoupler() : s(0), y(0)
	{
	}
	int16_t processNext(int16_t xi)
	{
		int32_t x = (int32_t)xi * 256;
		y = x - s;
		s = s + (x - s) / 512; // fc=1/(512*2*pi)=3.1085e-4=5.978Hz@fs=19.23kHz
		return (int16_t)(y / 256);
	}
};
#else // USE_CR
//
// Transposed Direct-Form II
//
//             b0
// x[n] ----+--|>--|+|------+----y[n]
//          |       | s1    |
//          |     |z-1|     |
//          |  b1   |  -a1  |
//          +--|>--|+|--<|--+
//
//        b0 + b1*z^-1   b0*z + b1
// H(z) = ------------ = ---------
//        1 + a1*z~-1     z + a1
//
// y = b0*x + s1; s1 = b1*x - a1*y;
//
// applying DC blocker configuration { a1 = -0.995, b0 = 1, b1 = -1 }:
// y=x+s1; s1=-x+0.995*y;
//
struct AcCoupler
{
	int32_t s1;
	AcCoupler() : s1(0)
	{
	}
	int16_t processNext(int16_t xi)
	{
		int32_t x = (int32_t)xi * 256;
		int32_t y = x + s1;
		s1 = -x + (y * 255) / 256;
		return (int16_t)(y / 256);
	}
};
#endif // USE_CR

struct PeakDetector
{
	int16_t threshold;
	uint16_t holdTime;
	uint16_t count;
	PeakDetector(int16_t vth, uint16_t thold)
		: threshold(vth)
		, holdTime(thold)
		, count(0)
	{
	}
	bool processNext(int16_t v)
	{
		v = tabs<int16_t>(v);
		if(threshold <= v) count = holdTime;
		else if(count) -- count;
		return 0 < count;
	}
};

struct Debouncer
{
	uint8_t bits; // the bit queue
	enum Edge { None, Rising, Falling } edge;
	bool high;
	Debouncer()
		: bits(0)
		, edge(None)
		, high(false)
	{
	}
	void reset(bool h)
	{
		edge = None;
		bits = h ? 0b11 : 0b00;
		high = h;
	}
	Edge processNext(bool h)
	{
		// assumes that called at 1~10ms intervals
		bits <<= 1;
		bits |= h ? 1 : 0;
		bits &= 0b11;
		edge = None;
		if(bits == 0b11)
		{
			if(!high) { high = true; edge = Rising; }
		}
		else if(bits == 0b00)
		{
			if(high) { high = false; edge = Falling; }
		}
		return edge;
	}
	bool isLow() const { return !high; }
	bool isHigh() const { return high; }
};

// --------------------------------------------------------------------------------
// the controller
// NOTE: the loop interval is generated from the free running ADC

// abbreviations
// * AL: Audio Level
// * PS: Power Supply
// * TG: Transmission Gate
// * XP: eXternal Power
// * HV: High Voltage
// * NL: Nominal Level
// * PL: Peak Level

// suffixes
// * M: Monitor input
// * S: Switch input
// * C: Control output
// * D: Display output
// * O: Output

// pin assignment
// * PA0: ADC ALM
// * PA1: DI ~XPM
// * PA2: AIN1 PSM
// * PA3: DI ~TGS
// * PA4: DI ~XPS
// * PA5: DI ~HVS
// * PA6: DO NLD
// * PA7: DO PLD
// * PB0: DO TGC
// * PB1: DO XPC
// * PB2: DO HVC
// * PB3: ~RESET

// inputs

#define PORT_XPM PORTA
#define PIN_XPM PINA
#define DDR_XPM DDRA
#define BIT_XPM PORTA1

#define PORT_TGS PORTA
#define PIN_TGS PINA
#define DDR_TGS DDRA
#define BIT_TGS PORTA3

#define PORT_XPS PORTA
#define PIN_XPS PINA
#define DDR_XPS DDRA
#define BIT_XPS PORTA4

#define PORT_HVS PORTA
#define PIN_HVS PINA
#define DDR_HVS DDRA
#define BIT_HVS PORTA5

// outputs

#define PORT_NLD PORTA
#define PIN_NLD PINA
#define DDR_NLD DDRA
#define BIT_NLD PORTA6

#define PORT_PLD PORTA
#define PIN_PLD PINA
#define DDR_PLD DDRA
#define BIT_PLD PORTA7

#define PORT_TGC PORTB
#define PIN_TGC PINB
#define DDR_TGC DDRB
#define BIT_TGC PORTB0

#define PORT_XPC PORTB
#define PIN_XPC PINB
#define DDR_XPC DDRB
#define BIT_XPC PORTB1

#define PORT_HVC PORTB
//#define PIN_HVC PINB
#define DDR_HVC DDRB
#define BIT_HVC PORTB2

struct Controller
{
	static const int WAIT_TGC = 10;
	static const int WAIT_XPC = 200;
	AcCoupler acCoupler;
	PeakDetector peakDetectorP;
	PeakDetector peakDetectorN;
	Debouncer tgsDebouncer, xpsDebouncer, hvsDebouncer; // pressed:low, released:high
	Debouncer psmDebouncer; // pass:low, fail:high
	uint8_t loopCount;
	uint8_t xpmWaitCount;
	bool tgc, xpc, hvc;
	Controller()
		: peakDetectorP(32000, 385) // threshold=-0.21dBFS, holdtime=20.02ms@fs=19.23kHz
		, peakDetectorN(128, 1924) // threshold=-48.2dBFS, holdtime=100.1ms@fs=19.23kHz
		, loopCount(0)
		, xpmWaitCount(0)
		, tgc(false)
		, xpc(false)
		, hvc(false)
	{
	}
	void configure()
	{
		// --------------------
		// clock prescaler
		// * fosc=8MHz, fclk=fosc/1=8MHz
		// CLKPR = (1<<CLKPCE); // enable prescaler change
		// CLKPR = (0b0000<<CLKPS0); // divisor=1
		clock_prescale_set(clock_div_1);
		// --------------------
		// peripherals, sleepmode
		// PRR = (1<<PRTIM1) | (1<<PRTIM0) | (1<<PRUSI); // disable usi, timer0, timer1
		// MCUCR = (0b01<<SM0); // sleepmode=ADC
		power_usi_disable();
		power_timer0_disable();
		power_timer1_disable();
		set_sleep_mode(SLEEP_MODE_ADC);
		// --------------------
		// port configuration
		DDRA  = (1<<BIT_PLD) | (1<<BIT_NLD);
		PORTA = (1<<BIT_HVS) | (1<<BIT_XPS) | (1<<BIT_TGS) | (1<<BIT_XPM);
		DDRB  = (1<<BIT_HVC) | (1<<BIT_XPC) | (1<<BIT_TGC);
		PORTB = 0;
		// --------------------
		// analog comparator, adc
		// * fclkadc=fclk/32=250kHz, fs=fclkadc/13=19.23kHz
		ACSR = (1<<ACBG); // analog comparator bandgap(1.1V) select
		ADMUX = (0b00<<REFS0) | (0b000000<<MUX0); // vref=vcc, ADC0 singleend
		ADCSRA = (1<<ADEN) | (1<<ADATE) | (1<<ADIE) | (0b101<<ADPS0); // adc enable, adc auto trigger enable, adc interrupt enable, adc prescaler=1/32
		ADCSRB = (0<<BIN) | (0<<ACME) | (1<<ADLAR) | (0b000<<ADTS0); // adc unipolar, disable analog comparator mux (use AIN1), adc left adjust, adc free running
		// where is the definition of AIN1D?
#if !defined AIN1D
#define AIN1D ADC2D
#endif
		DIDR0 = (1<<ADC0D) | (1<<AIN1D); // disable digital input on ADC0(PA0), AIN1(PA2)
	}
	void start()
	{
		// --------------------
		// startup blinking
		for(int i = 0; i < 4; ++ i)
		{
			setbit(PORT_PLD, BIT_PLD, 0);
			setbit(PORT_NLD, BIT_NLD, 1);
			_delay_ms(250);
			setbit(PORT_PLD, BIT_PLD, 1);
			setbit(PORT_NLD, BIT_NLD, 0);
			_delay_ms(250);
		}
		setbit(PORT_PLD, BIT_PLD, 0);
		setbit(PORT_NLD, BIT_NLD, 0);
		// --------------------
		// initialization
		tgsDebouncer.reset(PIN_TGS & (1<<BIT_TGS)); psmDebouncer.reset(ACSR & (1<<ACO)); tgc = tgsDebouncer.isLow() && psmDebouncer.isLow();
		xpsDebouncer.reset(PIN_XPS & (1<<BIT_XPS)); xpc = xpsDebouncer.isLow();
		hvsDebouncer.reset(PIN_HVS & (1<<BIT_HVS)); hvc = hvsDebouncer.isLow();
		setbit(PORT_HVC, BIT_HVC, hvc ? 1 : 0);
		setbit(PORT_XPC, BIT_XPC, xpc ? 1 : 0);
		_delay_ms(WAIT_XPC);
		setbit(PORT_TGC, BIT_TGC, tgc ? 1 : 0);
		_delay_ms(WAIT_TGC);
		// trigger the first conversion with the ADC initialization sequence
		ADCSRA |= (1<<ADSC);
	}
	void handleAdcIsr()
	{
		int16_t v = acCoupler.processNext((int16_t)ADCW - 32768);
		setbit(PORT_PLD, BIT_PLD, peakDetectorP.processNext(v) ? 1 : 0);
		setbit(PORT_NLD, BIT_NLD, peakDetectorN.processNext(v) ? 1 : 0);
	}
	void handleMainLoop()
	{
		++ loopCount;
		if(96 <= loopCount) // t=4.992ms@fs=19.23kHz
		{
			loopCount = 0;
			doperiodicjob();
		}
	}
	void settgc(bool v)
	{
		if(tgc == v) return;
		tgc = v;
		atomicsetbit(PORT_TGC, BIT_TGC, tgc ? 1 : 0);
		_delay_ms(WAIT_TGC);
	}
	void setxpc(bool v)
	{
		if(xpc == v) return;
		bool tgcsave = tgc;
		settgc(false);
		xpc = v;
		atomicsetbit(PORT_XPC, BIT_XPC, xpc ? 1 : 0);
		_delay_ms(WAIT_XPC);
		settgc(tgcsave);
		xpmWaitCount = 0;
	}
	void sethvc(bool v)
	{
		if(hvc == v) return;
		bool tgcsave = tgc;
		settgc(false);
		bool xpcsave = xpc;
		setxpc(false);
		hvc = v;
		atomicsetbit(PORT_HVC, BIT_HVC, hvc ? 1 : 0);
		setxpc(xpcsave);
		settgc(tgcsave);
	}
	void doperiodicjob()
	{
		if(tgsDebouncer.processNext(PIN_TGS & (1<<BIT_TGS)) || psmDebouncer.processNext(ACSR & (1<<ACO))) settgc(tgsDebouncer.isLow() && psmDebouncer.isLow());
		if(xpsDebouncer.processNext(PIN_XPS & (1<<BIT_XPS))) setxpc(xpsDebouncer.isLow());
		if(hvsDebouncer.processNext(PIN_HVS & (1<<BIT_HVS))) sethvc(hvsDebouncer.isLow());
		if(xpc)
		{
			if(!(PIN_XPM & (1<<BIT_XPM))) xpmWaitCount = 0;
			else if(xpmWaitCount < 100) ++ xpmWaitCount; // t=499.2ms@interval=4.992ms
			else setxpc(false);
		}
	}
} gController;

// --------------------------------------------------------------------------------
// entry points

int main(void)
{
	gController.configure();
	gController.start();
	sei();
	sleep_mode();
	while(1)
	{
		// woken up by the ADC interrupt
		gController.handleMainLoop();
		sleep_mode();
	}
	return 0;
}

ISR(ADC_vect)
{
	gController.handleAdcIsr();
}

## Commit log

2022-06-10 Update Schematics
2022-06-13 Update chassis-back.dxf
    remove nan elements
    [chassis-back.dxf]
2024-01-18 add machining data
    [chassis.dxf, frontpanel.dxf]
